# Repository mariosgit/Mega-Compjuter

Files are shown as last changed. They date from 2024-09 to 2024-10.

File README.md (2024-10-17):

# MEGA CompJU+TEr

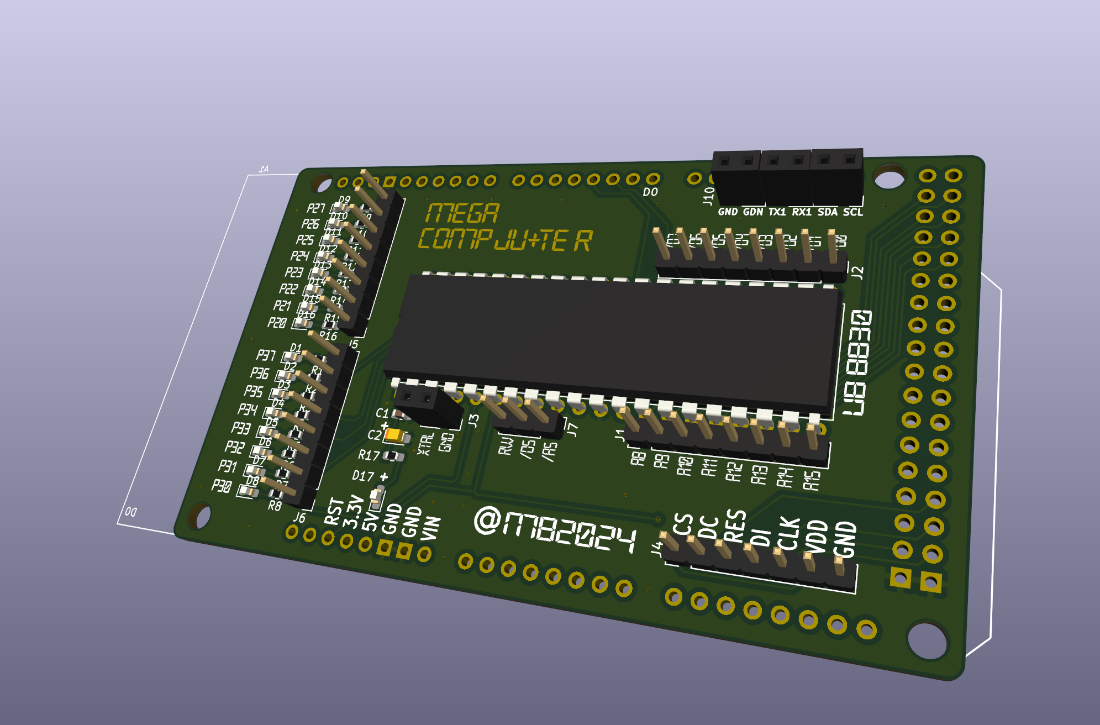
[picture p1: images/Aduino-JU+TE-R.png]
bild


# Status

Just an Idee. Made a basic PCB. Started experimenting...

# Wath's this ?

Arduino MEGA Shield with a UB8830 on top. The UB8833 is a Ostblock version of a Zilog Z8682 with a view quirks.

A bit like these things... http://8bitforce.com/projects/retroshield/ [Or here the Z80 code](https://gitlab.com/8bitforce/retroshield-arduino/-/blob/master/kz80/kz80_test/kz80_test.ino?ref_type=heads)

### Bugs / Improvements

* UB8833 reset(pin6) to some pin(45) ! keep it low until all ports initialize.
* LEDs for AS,RW,DS ?
* Fuse ? The Z8 needs 180mA !?

# Software

From Z8 datasheet...

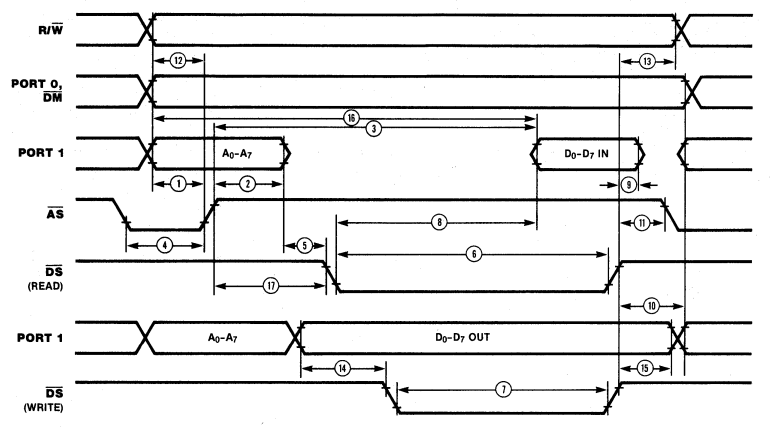
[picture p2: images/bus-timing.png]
bustiming


* When AS goes LOW->HI latch the low adr byte. And read and keep RW flag.
* When DS goes HIGH->LOW and RW is reading (HIGH) put data on the bus. 
* When DS goes low and writing, read the data, do something e.g. save to ram.
* Turn of Data output ??? When ??? Read data to DS 1 hold time is 0, so turn it off after DS goes high.

### Reset

8833 RESET-Eingang (vgl . Kapitel 1) .
Hat er nach eingeschwungene r
Spannungs- und Taktversorgun g
für mindestens **18** Taktperiode n
Nullpegel, erzeugt er im Innere n
des Einchip-Mikrorechners einige
festgelegte Zustände . 

in kurzes Pro-
gramm ab %000C im Test-ROM
konfiguriert Port 0, Port 1 und
P34 für den Anschluß des exter-
nen Speichers und springt au f
Adresse %0812

Der UB 8830 D
(UB 8831 D) besitzt auch be i
„normalem” Rücksetzen die ge-
nannten Interruptvektoren un d
springt auf die Adresse %0812,
wenn dort kein RAM bestückt is t
und P32 keine Verbindung zu P35
hat. 

Der Einchip-
Mikrorechner besitzt ein Test-
programm im internen ROM,
das sich für unsere Zwecke gut
ausnutzen läßt. Damit es vom
Prozessor ausgeführt wird, muß
eine Drahtbrücke die Port
Anschlüsse P32 und P35 ver-
binden. .......  0-Impulse
mit einer Breite von 11 μs
erscheinen. Jede Abweichung
von dieser Regel deutet auf
eine Fehlverbindung zwischen
benachbarten Leiterzügen. Bei
Inbetriebnahme mit Kopfhörer
o. ä. müssen diese 16 An-
schlüsse mit gleichlauten 5,45-
kHz-Tönen 

Der laeuft mit 8mhz, auf dem Arduino mit 70khz, Faktor 114, 1254us.

### First something ?

after applying reset for at least 3 clocks it started doing things
* AS, DS, RW go up and down
* But no data on the bus !? -> could the thing be running it's internal ROM first ? Then there should be a addr=0x0800 (ext reset vector) comming up some time.. When it reads 0 it would start @0 again ???
* Oszi say it starts reading and writing to 0x1012 after about 173 initial clocks. it writes 0xff ?

# PCB

| ATMega Pin Port | UB8833 | Comments |
|---|---|---|
| PA | AdrHi | hi adr byte |
| PC | AdrLow/Data bus | multiplexed Data/Adr bus |
| | | |
| D2(int0) | AS | Adr strobe, Lo->Hi store the low adr |
| D3(int1) | DS | Data strobe, ?? |
| | | |
| D46/PL3(pwm pin) | XTAL | Clock |
| D47/PL2 | RW | Read/Write indication |

| ATMega Pin | Display |
|---|---|
| D53 | CS |
| D49 | DC |
| D51(mosi) | DI |
| D52(sclk) | CLK |

# Refs

https://github.com/boert/JU-TE-Computer

https://hc-ddr.hucki.net/wiki/doku.php/tiny/dokumentation 

https://www.robotrontechnik.de/html/forum/thwb/showtopic.php?threadid=16374

https://hackaday.com/2020/07/17/a-z80-board-with-very-few-parts/

http://bitsavers.informatik.uni-stuttgart.de/components/zilog/z8/Z8681_Data_Sheet_Mar83.pdf

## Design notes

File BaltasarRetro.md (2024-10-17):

From [Arduino and ZiLOG Z80](https://baltazarstudios.com/webshare/Z80_dongle.ino.html)

```
//------------------------------------------------------------------------
// This Arduino sketch should be used with a Mega board connected to a
// dongle hosting a Z80 CPU. The Arduino fully controls and senses all
// Z80 CPU pins. This software runs physical Z80 CPU by providing clock
// ticks and setting various control pins.
//
// There is a limited RAM buffer simulated by this sketch. All Z80 memory
// accesses are directed to use that buffer.
//
// Address and data buses from Z80 are connected to analog Arduino pins.
// Along with a resistor network on the dongle, this allows the software
// to sense when Z80 tri-states those two buses.
//
// Notes:
//      - Use serial set to 115200
//      - In the Arduino serial monitor window, set line ending to "CR"
//      - Memory access is simulated using a 256-byte pseudo-RAM memory
//      - I/O map is _not_ implemented. Reads will return whatever happens
//        to be on the data bus
//
// Copyright 2014 by Goran Devic
// This source code is released under the GPL v2 software license.
//------------------------------------------------------------------------
#include <stdarg.h>
#include "WString.h"

// Define Arduino Mega pins that are connected to a Z80 dongle board.
// Pin numbers appear out-of-order, but they cleanly connect in complete
// blocks to sets of pins on Arduino Mega! This will become obvious once
// you start connecting them...
#define DB0         A9      // DB pin line-up on a Z80 is a bit swizzled...
#define DB1         A8
#define DB2         A11
#define DB3         A14
#define DB4         A15
#define DB5         A13
#define DB6         A12
#define DB7         A10
// Address bus pins from Z80 are connected to A0..A7 on Arduino.

#define INT         52      // This is a block of control signals from the
#define NMI         50      // bottom-left corner of Z80
#define HALT        48
#define MREQ        46
#define IORQ        44

#define RFSH        53      // This is a block of control signals from the
#define M1          51      // bottom-right corner of Z80
#define RESET       49
#define BUSRQ       47
#define WAIT        45
#define BUSAK       43
#define WR          41
#define RD          39

#define CLK         13      // Clock is also toggling Arduino LED (fast, though)

// Tri-state detection values: the values that are read on analog pins
// sensing the "high-Z" will differ based on the resistor values that make
// up your voltage divider. Print your particular readings and adjust these:
#define HI_Z_LOW    50      // Upper "0" value; low tri-state boundary
#define HI_Z_HIGH   600     // Low "1" value; upper tri-state boundary

// Control *output* pins of Z80, we read them into these variables
int  halt;
int  mreq;
int  iorq;
int  rfsh;
int  m1;
int  busak;
int  wr;
int  rd;

// Control *input* pins of Z80, we write them into the dongle
int zint = 1;
int nmi = 1;
int reset = 1;
int busrq = 1;
int wait = 1;

// Content of address and data wires
int ab;
byte db;

// Clock counter after reset
int clkCount;
int clkCountHi;

// T-cycle counter
int T;
int Mlast;

// M1-cycle counter
int m1Count;

// Detection if the address or data bus is tri-stated
bool abTristated = false;
bool dbTristated = false;

// Simulation control variables
bool running = 1;           // Simulation is running or is stopped
int traceShowBothPhases;    // Show both phases of a clock cycle
int traceRefresh;           // Trace refresh cycles
int tracePause;             // Pause for a key press every so many clocks
int tracePauseCount;        // Current clock count for tracePause
int stopAtClk;              // Stop the simulation after this many clocks
int stopAtM1;               // Stop at a specific M1 cycle number
int stopAtHalt;             // Stop when HALT signal gets active
int intAtClk;               // Issue INT signal at that clock number
int nmiAtClk;               // Issue NMI signal at that clock number
int busrqAtClk;             // Issue BUSRQ signal at that clock number
int resetAtClk;             // Issue RESET signal at that clock number
int waitAtClk;              // Issue WAIT signal at that clock number
int clearAtClk;             // Clear all control signals at that clock number
byte iorqVector;            // Push IORQ vector (default is FF)

// Buffer containing RAM memory for Z80 to access
byte ram[256];

// Temp buffer to store input line
#define TEMP_SIZE   512
char temp[TEMP_SIZE];

// Temp buffer to store extra dump information
char extraInfo[64] = { "" };

// Utility function to provide a meaningful printf to a serial port
void p(char *fmt, ... ){
    char tmp[256];          // resulting string limited to 256 chars
    va_list args;
    va_start (args, fmt );
    vsnprintf(tmp, 256, fmt, args);
    va_end (args);
    Serial.print(tmp);
}

// Read and return one ASCII hex value from a string
byte hex(char *s){
    byte nibbleH = (*s - '0') & ~(1<<5);
    byte nibbleL = (*(s+1) - '0') & ~(1<<5);
    if (nibbleH>9) nibbleH -= 7;
    if (nibbleL>9) nibbleL -= 7;
    return (nibbleH << 4) | nibbleL;
}

// Read and return one ASCII hex value from a temp buffer given the index
// of that hex number. This is used only to read Intel HEX format buffer.
byte hexFromTemp(char *pTemp, int index)
{
    int start = (index*2)+1;
    return hex(pTemp + start);
}

// -----------------------------------------------------------
// Arduino initialization entry point
// -----------------------------------------------------------
void setup()
{
    Serial.begin(115200);
    Serial.flush();
    Serial.setTimeout(1000*60*60);

    ResetSimulationVars();

    // By default, all Arduino pins are set as inputs
    // Configure all output pins, *inputs* into Z80
    pinMode(CLK, OUTPUT);
    digitalWrite(CLK, HIGH);
    pinMode(INT, OUTPUT);
    pinMode(NMI, OUTPUT);
    pinMode(RESET, OUTPUT);
    pinMode(BUSRQ, OUTPUT);
    pinMode(WAIT, OUTPUT);
    WriteControlPins();

    // Perform a Z80 CPU reset
    DoReset();
}

// Resets all simulation variables to their defaults
void ResetSimulationVars()
{
    traceShowBothPhases = 0;// Show both phases of a clock cycle
    traceRefresh = 1;       // Trace refresh cycles
    tracePause = -1;        // Pause for a keypress every so many clocks
    stopAtClk = 40;         // Stop the simulation after this many clocks
    stopAtM1 = -1;          // Stop at a specific M1 cycle number
    stopAtHalt = 1;         // Stop when HALT signal gets active
    intAtClk = -1;          // Issue INT signal at that clock number
    nmiAtClk = -1;          // Issue NMI signal at that clock number
    busrqAtClk = -1;        // Issue BUSRQ signal at that clock number
    resetAtClk = -1;        // Issue RESET signal at that clock number
    waitAtClk = -1;         // Issue WAIT signal at that clock number
    clearAtClk = -1;        // Clear all control signals at that clock number
    iorqVector = 0xFF;      // Push IORQ vector
}

// Issue a RESET sequence to Z80 and reset internal counters
void DoReset()
{
    p("\r\n:Starting the clock\r\n");
    digitalWrite(RESET, LOW);    delay(1);
    // Reset should be kept low for 3 full clock cycles
    for(int i=0; i<3; i++)
    {
        digitalWrite(CLK, HIGH); delay(1);
        digitalWrite(CLK, LOW);  delay(1);
    }
    p(":Releasing RESET\r\n");
    digitalWrite(RESET, HIGH);   delay(1);
    // Do not count initial 2 clocks after the reset
    clkCount = -2;
    T = 0;
    Mlast = 1;
    tracePauseCount = 0;
    m1Count = 0;
}

// Write all control pins into the Z80 dongle
void WriteControlPins()
{
    digitalWrite(INT, zint ? HIGH : LOW);
    digitalWrite(NMI, nmi ? HIGH : LOW);
    digitalWrite(RESET, reset ? HIGH : LOW);
    digitalWrite(BUSRQ, busrq ? HIGH : LOW);
    digitalWrite(WAIT,  wait ? HIGH : LOW);
}

// Set new data value into the Z80 data bus
void SetDataToDB(byte data)
{
    pinMode(DB0, OUTPUT);
    pinMode(DB1, OUTPUT);
    pinMode(DB2, OUTPUT);
    pinMode(DB3, OUTPUT);
    pinMode(DB4, OUTPUT);
    pinMode(DB5, OUTPUT);
    pinMode(DB6, OUTPUT);
    pinMode(DB7, OUTPUT);

    digitalWrite(DB0, (data & (1<<0)) ? HIGH : LOW);
    digitalWrite(DB1, (data & (1<<1)) ? HIGH : LOW);
    digitalWrite(DB2, (data & (1<<2)) ? HIGH : LOW);
    digitalWrite(DB3, (data & (1<<3)) ? HIGH : LOW);
    digitalWrite(DB4, (data & (1<<4)) ? HIGH : LOW);
    digitalWrite(DB5, (data & (1<<5)) ? HIGH : LOW);
    digitalWrite(DB6, (data & (1<<6)) ? HIGH : LOW);
    digitalWrite(DB7, (data & (1<<7)) ? HIGH : LOW);
    db = data;
    dbTristated = false;
}

// Read Z80 data bus and store into db variable
void GetDataFromDB()
{
    pinMode(DB0, INPUT);
    pinMode(DB1, INPUT);
    pinMode(DB2, INPUT);
    pinMode(DB3, INPUT);
    pinMode(DB4, INPUT);
    pinMode(DB5, INPUT);
    pinMode(DB6, INPUT);
    pinMode(DB7, INPUT);

    digitalWrite(DB0, LOW);
    digitalWrite(DB1, LOW);
    digitalWrite(DB2, LOW);
    digitalWrite(DB3, LOW);
    digitalWrite(DB4, LOW);
    digitalWrite(DB5, LOW);
    digitalWrite(DB6, LOW);
    digitalWrite(DB7, LOW);

    // Detect if the data bus is tri-stated
    delay(1);
    int test0 = analogRead(DB0);
    // These numbers might need to be adjusted for each Arduino board
    dbTristated = test0>HI_Z_LOW && test0<HI_Z_HIGH;

    byte d0 = digitalRead(DB0);
    byte d1 = digitalRead(DB1);
    byte d2 = digitalRead(DB2);
    byte d3 = digitalRead(DB3);
    byte d4 = digitalRead(DB4);
    byte d5 = digitalRead(DB5);
    byte d6 = digitalRead(DB6);
    byte d7 = digitalRead(DB7);
    db = (d7<<7)|(d6<<6)|(d5<<5)|(d4<<4)|(d3<<3)|(d2<<2)|(d1<<1)|d0;
}

// Read a value of Z80 address bus and store it into the ab variable.
// In addition, try to detect when a bus is tri-stated and write 0xFFF if so.
void GetAddressFromAB()
{
    // Detect if the address bus is tri-stated
    int test0 = analogRead(A0);
    // These numbers might need to be adjusted for each Arduino board
    abTristated = test0>HI_Z_LOW && test0<HI_Z_HIGH;

    int a0 = digitalRead(A0);
    int a1 = digitalRead(A1);
    int a2 = digitalRead(A2);
    int a3 = digitalRead(A3);
    int a4 = digitalRead(A4);
    int a5 = digitalRead(A5);
    int a6 = digitalRead(A6);
    int a7 = digitalRead(A7);
    ab = (a7<<7)|(a6<<6)|(a5<<5)|(a4<<4)|(a3<<3)|(a2<<2)|(a1<<1)|a0;
}

// Read all control pins on the Z80 and store them into internal variables
void ReadControlState()
{
    halt  = digitalRead(HALT);
    mreq  = digitalRead(MREQ);
    iorq  = digitalRead(IORQ);
    rfsh  = digitalRead(RFSH);
    m1    = digitalRead(M1);
    busak = digitalRead(BUSAK);
    wr    = digitalRead(WR);
    rd    = digitalRead(RD);
}

// Dump the Z80 state as stored in internal variables
void DumpState(bool suppress)
{
    if (!suppress)
    {
        // Select your character for tri-stated bus
        char abStr[4] = { "---" };
        char dbStr[3] = { "--" };
        if (!abTristated) sprintf(abStr, "%03X", ab);
        if (!dbTristated) sprintf(dbStr, "%02X", db);
        if (T==1 && clkCountHi)
            p("-----------------------------------------------------------+\r\n");
        p("#%03d%c T%-2d AB:%s DB:%s  %s %s %s %s %s %s %s %s |%s%s%s%s %s\r\n",
        clkCount<0? 0 : clkCount, clkCountHi ? 'H' : 'L', T,
        abStr, dbStr,
        m1?"  ":"M1", rfsh?"    ":"RFSH", mreq?"    ":"MREQ", rd?"  ":"RD", wr?"  ":"WR", iorq?"    ":"IORQ", busak?"     ":"BUSAK",halt?"    ":"HALT",
        zint?"":"[INT]", nmi?"":"[NMI]", busrq?"":"[BUSRQ]", wait?"":"[WAIT]",
        extraInfo);
    }
    extraInfo[0] = 0;
}

// -----------------------------------------------------------
// Main loop routine runs over and over again forever
// -----------------------------------------------------------
void loop()
{
    //--------------------------------------------------------
    // Clock goes high
    //--------------------------------------------------------
    delay(1); digitalWrite(CLK, HIGH); delay(1);

    clkCountHi = 1;
    clkCount++;
    T++;
    tracePauseCount++;
    ReadControlState();
    GetAddressFromAB();
    if (Mlast==1 && m1==0)
        T = 1, m1Count++;
    Mlast = m1;
    bool suppressDump = false;
    if (!traceRefresh & !rfsh) suppressDump = true;

    // If the number of M1 cycles has been reached, skip the rest since we dont
    // want to execute this M1 phase
    if (m1Count==stopAtM1)
    {
        sprintf(extraInfo, "Number of M1 cycles reached"), running = false;
        p("-----------------------------------------------------------+\r\n");
        goto control;
    }

    // If the address is tri-stated, skip checking various combinations of
    // control signals since they may also be floating and we can't detect that
    if (!abTristated)
    {
        // Simulate read from RAM
        if (!mreq && !rd)
        {
            SetDataToDB(ram[ab & 0xFF]);
            if (!m1)
                sprintf(extraInfo, "Opcode read from %03X -> %02X", ab, ram[ab & 0xFF]);
            else
                sprintf(extraInfo, "Memory read from %03X -> %02X", ab, ram[ab & 0xFF]);
        }
        else
        // Simulate interrupt requesting a vector
        if (!m1 && !iorq)
        {
            SetDataToDB(iorqVector);
            sprintf(extraInfo, "Pushing vector %02X", iorqVector);
        }
        else
            GetDataFromDB();

        // Simulate write to RAM
        if (!mreq && !wr)
        {
            ram[ab & 0xFF] = db;
            sprintf(extraInfo, "Memory write to  %03X <- %02X", ab, db);
        }

        // Detect I/O read: We don't place anything on the bus
        if (!iorq && !rd)
        {
            sprintf(extraInfo, "I/O read from %03X", ab);
        }

        // Detect I/O write
        if (!iorq && !wr)
        {
            sprintf(extraInfo, "I/O write to %03X <- %02X", ab, db);
        }

        // Capture memory refresh cycle
        if (!mreq && !rfsh)
        {
            sprintf(extraInfo, "Refresh address  %03X", ab);
        }
    }
    else
        GetDataFromDB();

    DumpState(suppressDump);

    // If the user wanted to pause simulation after a certain number of
    // clocks, handle it here. If the key pressed to continue was not Enter,
    // stop the simulation to issue that command
    if (tracePause==tracePauseCount)
    {
        while(Serial.available()==0) ;
        if (Serial.peek()!='\r')
            sprintf(extraInfo, "Continue keypress was not Enter"), running = false;
        else
            Serial.read();
        tracePauseCount = 0;
    }

    //--------------------------------------------------------
    // Clock goes low
    //--------------------------------------------------------
    delay(1); digitalWrite(CLK, LOW); delay(1);

    clkCountHi = 0;
    if (traceShowBothPhases)
    {
        ReadControlState();
        GetAddressFromAB();
        DumpState(suppressDump);
    }

    // Perform various actions at the requested clock number
    // if the count is positive (we start it at -2 to skip initial 2T)
    if (clkCount>=0)
    {
        if (clkCount==intAtClk) zint = 0;
        if (clkCount==nmiAtClk) nmi = 0;
        if (clkCount==busrqAtClk) busrq = 0;
        if (clkCount==resetAtClk) reset = 0;
        if (clkCount==waitAtClk) wait = 0;
        // De-assert all control pins at this clock number
        if (clkCount==clearAtClk)
            zint = nmi = busrq = reset = wait = 1;
        WriteControlPins();

        // Stop the simulation under some conditions
        if (clkCount==stopAtClk)
            sprintf(extraInfo, "Number of clocks reached"), running = false;
        if (stopAtHalt&!halt)
            sprintf(extraInfo, "HALT instruction"), running = false;
    }

    //--------------------------------------------------------
    // Trace/simulation control handler
    //--------------------------------------------------------
control:
    if (!running)
    {
        p(":Simulation stopped: %s\r\n", extraInfo);
        extraInfo[0] = 0;
        digitalWrite(CLK, HIGH);
        zint = nmi = busrq = wait = 1;
        WriteControlPins();

        while(!running)
        {
            // Expect a command from the serial port
            if (Serial.available()>0)
            {
                memset(temp, 0, TEMP_SIZE);
                Serial.readBytesUntil('\r', temp, TEMP_SIZE-1);

                // Option ":"  : this is not really a user option. This is used to
                //               Intel HEX format values into the RAM buffer
                // Multiple lines may be pasted. They are separated by a space character.
                char *pTemp = temp;
                while (*pTemp==':')
                {
                    byte bytes = hexFromTemp(pTemp, 0);
                    if (bytes>0)
                    {
                        int address = (hexFromTemp(pTemp, 1)<<8) + hexFromTemp(pTemp, 2);
                        byte recordType = hexFromTemp(pTemp, 3);
                        p("%04X:", address);
                        for (int i=0; i<bytes; i++)
                        {
                            ram[(address + i) & 0xFF] = hexFromTemp(pTemp, 4+i);
                            p(" %02X", hexFromTemp(pTemp, 4+i));
                        }
                        p("\r\n");
                    }
                    pTemp += bytes*2 + 12;  // Skip to the next possible line of hex entry
                }
                // Option "r"  : reset and run the simulation
                if (temp[0]=='r')
                {
                    // If the variable 9 (Issue RESET) is not set, perform a RESET and run the simulation.
                    // If the variable was set, skip reset sequence since we might be testing it.
                    if (resetAtClk<0)
                        DoReset();
                    running = true;
                }
                // Option "sc" : clear simulation variables to their default values
                if (temp[0]=='s' && temp[1]=='c')
                {
                    ResetSimulationVars();
                    temp[1] = 0;            // Proceed to dump all variables...
                }
                // Option "s"  : show and set internal control variables
                if (temp[0]=='s' && temp[1]!='c')
                {
                    // Show or set the simulation parameters
                    int var = 0, value;
                    int args = sscanf(&temp[1], "%d %d\r\n", &var, &value);
                    // Parameter for the option #12 is read in as a hex; others are decimal by default
                    if (var==12)
                        args = sscanf(&temp[1], "%d %x\r\n", &var, &value);
                    if (args==2)
                    {
                        if (var==0) traceShowBothPhases = value;
                        if (var==1) traceRefresh = value;
                        if (var==2) tracePause = value;
                        if (var==3) stopAtClk = value;
                        if (var==4) stopAtM1 = value;
                        if (var==5) stopAtHalt = value;
                        if (var==6) intAtClk = value;
                        if (var==7) nmiAtClk = value;
                        if (var==8) busrqAtClk = value;
                        if (var==9) resetAtClk = value;
                        if (var==10) waitAtClk = value;
                        if (var==11) clearAtClk = value;
                        if (var==12) iorqVector = value & 0xFF;
                    }
                    p("------ Simulation variables ------\r\n");
                    p("#0  Trace both clock phases  = %d\r\n", traceShowBothPhases);
                    p("#1  Trace refresh cycles     = %d\r\n", traceRefresh);
                    p("#2  Pause for keypress every = %d\r\n", tracePause);
                    p("#3  Stop after clock #       = %d\r\n", stopAtClk);
                    p("#4  Stop after # M1 cycles   = %d\r\n", stopAtM1);
                    p("#5  Stop at HALT             = %d\r\n", stopAtHalt);
                    p("#6  Issue INT at clock #     = %d\r\n", intAtClk);
                    p("#7  Issue NMI at clock #     = %d\r\n", nmiAtClk);
                    p("#8  Issue BUSRQ at clock #   = %d\r\n", busrqAtClk);
                    p("#9  Issue RESET at clock #   = %d\r\n", resetAtClk);
                    p("#10 Issue WAIT at clock #    = %d\r\n", waitAtClk);
                    p("#11 Clear all at clock #     = %d\r\n", clearAtClk);
                    p("#12 Push IORQ vector #(hex)  = %2X\r\n", iorqVector);
                }
                // Option "m"  : dump RAM memory
                if (temp[0]=='m' && temp[1]!='c')
                {
                    // Dump the content of a RAM buffer
                    p("    00 01 02 03 04 05 06 07 08 09 0A 0B 0C 0D 0E 0F\r\n");
                    p("   +-----------------------------------------------\r\n");
                    for(int i=0; i<16; i++)
                    {
                        p("%02X |", i);
                        for(int j=0; j<16; j++)
                        {
                            p("%02X ", ram[i*16+j]);
                        }
                        p("\r\n");
                    }
                }
                // Option "mc"  : clear RAM memory
                if (temp[0]=='m' && temp[1]=='c')
                {
                    memset(ram, 0, sizeof(ram));
                    p("RAM cleared\r\n");
                }
                // Option "?"  : print help
                if (temp[0]=='?' || temp[0]=='h')
                {
                    p("s            - show simulation variables\r\n");
                    p("s #var value - set simulation variable number to a value\r\n");
                    p("sc           - clear simulation variables to their default values\r\n");
                    p("r            - restart the simulation\r\n");
                    p(":INTEL-HEX   - reload RAM buffer with a given data stream\r\n");
                    p("m            - dump the content of the RAM buffer\r\n");
                    p("mc           - clear the RAM buffer\r\n");
                }
            }
        }
    }
}

```

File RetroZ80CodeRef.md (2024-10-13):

# Ref..

 http://8bitforce.com/projects/retroshield/ [Or here the Z80 code](https://gitlab.com/8bitforce/retroshield-arduino/-/blob/master/kz80/kz80_test/kz80_test.ino?ref_type=heads)

```
////////////////////////////////////////////////////////////////////
// Z80 RetroShield Code
// 2019/02/11
// Version 0.1
// Erturk Kocalar

// The MIT License (MIT)

// Copyright (c) 2019 Erturk Kocalar, 8Bitforce.com

// Permission is hereby granted, free of charge, to any person obtaining a copy
// of this software and associated documentation files (the "Software"), to deal
// in the Software without restriction, including without limitation the rights
// to use, copy, modify, merge, publish, distribute, sublicense, and/or sell
// copies of the Software, and to permit persons to whom the Software is
// furnished to do so, subject to the following conditions:

// The above copyright notice and this permission notice shall be included in all
// copies or substantial portions of the Software.

// THE SOFTWARE IS PROVIDED "AS IS", WITHOUT WARRANTY OF ANY KIND, EXPRESS OR
// IMPLIED, INCLUDING BUT NOT LIMITED TO THE WARRANTIES OF MERCHANTABILITY,
// FITNESS FOR A PARTICULAR PURPOSE AND NONINFRINGEMENT. IN NO EVENT SHALL THE
// AUTHORS OR COPYRIGHT HOLDERS BE LIABLE FOR ANY CLAIM, DAMAGES OR OTHER
// LIABILITY, WHETHER IN AN ACTION OF CONTRACT, TORT OR OTHERWISE, ARISING FROM,
// OUT OF OR IN CONNECTION WITH THE SOFTWARE OR THE USE OR OTHER DEALINGS IN THE
// SOFTWARE.

////////////////////////////////////////////////////////////////////
// include the library code:
////////////////////////////////////////////////////////////////////

#include <LiquidCrystal.h>
#include <avr/pgmspace.h>

// Set this to enable outputing ADDR, DATA, Freq
// on LCD and use UP/DOWN for controlling RESET#.
#define USE_LCDKEYPAD 0

// Set this to output memory operations during timer clock.
// warning: this will slow down the timer interrupt, so adjust clock
//          freq accordingly.
#define outputDEBUG 0

////////////////////////////////////////////////////////////////////
// Configuration
////////////////////////////////////////////////////////////////////

/*
  The circuit:
 * LCD RS pin to digital pin 12
 * LCD Enable pin to digital pin 11
 * LCD D4 pin to digital pin 5
 * LCD D5 pin to digital pin 4
 * LCD D6 pin to digital pin 3
 * LCD D7 pin to digital pin 2
 * LCD R/W pin to ground
 * 10K resistor:
 * ends to +5V and ground
 * wiper to LCD VO pin (pin 3)
*/

#define LCD_RS  8
#define LCD_EN  9
#define LCD_D4  4
#define LCD_D5  5
#define LCD_D6  6
#define LCD_D7  7
#define LCD_BL  10
#define LCD_BTN  0

#define NUM_KEYS   5
#define BTN_DEBOUNCE 10
#define BTN_RIGHT  0
#define BTN_UP     1
#define BTN_DOWN   2
#define BTN_LEFT   3
#define BTN_SELECT 4
const int adc_key_val[NUM_KEYS] = { 30, 180, 360, 535, 760 };
int key = -1;
int oldkey = -1;
boolean BTN_PRESS = 0;
boolean BTN_RELEASE = 0;

////////////////////////////////////////////////////////////////////
// initialize the library with the numbers of the interface pins
LiquidCrystal lcd(LCD_RS, LCD_EN, LCD_D4, LCD_D5, LCD_D6, LCD_D7);

////////////////////////////////////////////////////////////////////
// My Variables
////////////////////////////////////////////////////////////////////

int backlightSet = 25;

////////////////////////////////////////////////////////////////////
// Z80 DEFINITIONS
////////////////////////////////////////////////////////////////////

// Z80 HW CONSTRAINTS
// !!! TODO !!!
// 1- RESET_N must be asserted at least 2 clock cycles.
// 2- CLK can not be low more than 5 microseconds.  Can be high indefinitely.
//

////////////////////////////////////////////////////////////////////
// Monitor Code
////////////////////////////////////////////////////////////////////
// static const unsigned char 
PROGMEM const unsigned char rom_bin[] = {
 0x31,0xFF,0x83,0xED,0x56,0xFB,0x3E,0x4D,
 0xD3,0x01,0x3E,0x37,0xD3,0x01,0xC3,0x3C,
 0x00,0x00,0x00,0x00,0x00,0x00,0x00,0x00,
 0x00,0x00,0x00,0x00,0x00,0x00,0x00,0x00,
 0x00,0x00,0x00,0x00,0x00,0x00,0x00,0x00,
 0x00,0x00,0x00,0x00,0x00,0x00,0x00,0x00,
 0x00,0x00,0x00,0x00,0x00,0x00,0x00,0x00,
 0xF3,0xFB,0xED,0x4D,0x21,0x51,0x00,0x06,
 0x1D,0x7E,0xCD,0x6E,0x00,0x23,0x10,0xF9,
 0xCD,0x7A,0x00,0xCD,0x6E,0x00,0xC3,0x48,
 0x00,0x0A,0x0D,0x54,0x58,0x44,0x3A,0x20,
 0x20,0x20,0x20,0x0A,0x0D,0x52,0x58,0x44,
 0x3A,0x20,0x20,0x20,0x0A,0x0D,0x52,0x65,
 0x61,0x64,0x79,0x3E,0x0A,0x0D,0xF5,0xDB,
 0x01,0xE6,0x01,0xCA,0x6F,0x00,0xF1,0xD3,
 0x00,0xC9,0xDB,0x01,0xE6,0x02,0xCA,0x7A,
 0x00,0xDB,0x00,0xC9
};

////////////////////////////////////////////////////////////////////
// MEMORY LAYOUT
////////////////////////////////////////////////////////////////////

// ROM(s) (Monitor)
#define ROM_START   0x0000
#define ROM_END     (ROM_START+sizeof(rom_bin))

// RAM (4KB)
#define RAM_START   0x8000
#define RAM_END     0x8FFF
byte    RAM[RAM_END-RAM_START+1];

////////////////////////////////////////////////////////////////////
// 8251 Peripheral
// emulate just enough so keyboard/display works thru serial port.
////////////////////////////////////////////////////////////////////
//

#define ADDR_8251_DATA          0x00
#define ADDR_8251_MODCMD        0x01

#define STATE_8251_RESET        0x01
#define STATE_8251_INITIALIZED  0x00
#define CMD_8251_INTERNAL_RESET 0x40
#define CMD_8251_RTS            0x20
#define CMD_8251_DTR            0x02
#define STAT_8251_TxRDY         0x01
#define STAT_8251_RxRDY         0x02
#define STAT_8251_TxE           0x04
#define STAT_DSR                0x80

byte reg8251_STATE;      // register to keep track of 8251 state: reset or initialized
byte reg8251_MODE;
byte reg8251_COMMAND;
byte reg8251_STATUS;
byte reg8251_DATA;

////////////////////////////////////////////////////////////////////
// Z80 Processor Control
////////////////////////////////////////////////////////////////////
//

/* Digital Pin Assignments */
#define DATA_OUT (PORTL)
#define DATA_IN  (PINL)
#define ADDR_H   (PINC)
#define ADDR_L   (PINA)
#define ADDR     ((unsigned int) (ADDR_H << 8 | ADDR_L))

#define uP_RESET_N  38
#define uP_MREQ_N   41
#define uP_IORQ_N   39
#define uP_RD_N     53
#define uP_WR_N     40
#define uP_NMI_N    51
#define uP_INT_N    50
#define uP_CLK      52

// Fast routines to drive clock signals high/low; faster than digitalWrite
// required to meet >100kHz clock
//
#define CLK_HIGH      (PORTB = PORTB | 0x02)
#define CLK_LOW       (PORTB = PORTB & 0xFC)
#define STATE_RD_N    (PINB & 0x01)
#define STATE_WR_N    (PING & 0x02)
#define STATE_MREQ_N  (PING & 0x01)
#define STATE_IORQ_N  (PING & 0x04)

#define DIR_IN  0x00
#define DIR_OUT 0xFF
#define DATA_DIR   DDRL
#define ADDR_H_DIR DDRC
#define ADDR_L_DIR DDRA

unsigned long clock_cycle_count;
unsigned long uP_start_millis;
unsigned long uP_stop_millis;
unsigned int  uP_ADDR;
byte uP_DATA;

void uP_init()
{
  // Set directions
  DATA_DIR = DIR_IN;
  ADDR_H_DIR = DIR_IN;
  ADDR_L_DIR = DIR_IN;
  
  pinMode(uP_RESET_N, OUTPUT);
  pinMode(uP_WR_N, INPUT);
  pinMode(uP_RD_N, INPUT);
  pinMode(uP_MREQ_N, INPUT);
  pinMode(uP_IORQ_N, INPUT);
  pinMode(uP_INT_N, OUTPUT);
  pinMode(uP_NMI_N, OUTPUT);
  pinMode(uP_CLK, OUTPUT);
  
  uP_assert_reset();
  digitalWrite(uP_CLK, LOW);
  
  clock_cycle_count = 0;
  uP_start_millis = millis();
  // Next State
}

void intel8251_init()
{
  reg8251_STATE     = STATE_8251_RESET;
  reg8251_MODE      = 0b01001101;       // async mode: 1x baudrate, 8n1
  reg8251_COMMAND   = 0b00100111;       // enable tx/rx; assert DTR & RTS
  reg8251_STATUS    = 0b10000101;       // TxRDY, TxE, DSR (ready for operation). RxRDY=0
  reg8251_DATA      = 0x00;
}

void uP_assert_reset()
{
  // Drive RESET conditions
  digitalWrite(uP_RESET_N, LOW);
  digitalWrite(uP_INT_N, HIGH);
  digitalWrite(uP_NMI_N, HIGH);
}

void uP_release_reset()
{
  // Drive RESET conditions
  digitalWrite(uP_RESET_N, HIGH);
}

////////////////////////////////////////////////////////////////////
// Processor Control Loop
////////////////////////////////////////////////////////////////////
// This is where the action is.
// it reads processor control signals and acts accordingly.
//
// Z80 takes multiple cycles to accomplish each rd/write.
// so if we act on IORQ, RD, WR at every clock cycle, then
// we perform erroneous extra IO read/writes.
// FIX WR: perform IO write only on IORQ/WR falling edge.
// FIX RD: perform IO read only on IORQ/RD falling edge.
byte prevIORQ = 0;
byte prevMREQ = 0;
byte prevDATA = 0;

ISR(TIMER1_COMPA_vect)
{ 
  CLK_HIGH;    // CLK goes high
  
  uP_ADDR = ADDR;
  
  // unlike memory mapped devices in 6502 & 6809,
  // Z80 bus has two modes: Memory (MREQ_N) and IO (IORQ_N)

  //////////////////////////////////////////////////////////////////////
  // Memory Access?
  if (!STATE_MREQ_N)    
  {

    // Memory Read?
    if (!STATE_RD_N)
    {
      // change DATA port to output to uP:
      DATA_DIR = DIR_OUT;

      // ROM?
      if ( (ROM_START <= uP_ADDR) && (uP_ADDR <= ROM_END) )
        DATA_OUT = pgm_read_byte_near(rom_bin + (uP_ADDR - ROM_START));
      else
      // RAM?
      if ( (uP_ADDR <= RAM_END) && (RAM_START <= uP_ADDR) )
        DATA_OUT = RAM[uP_ADDR - RAM_START];

    } else
    // Write?
    if (!STATE_WR_N)
    {
      // Memory Write
      if ( (RAM_START <= uP_ADDR) && (uP_ADDR <= RAM_END) )
        RAM[uP_ADDR - RAM_START] = DATA_IN;
    }

    if (outputDEBUG)
    {
      char tmp[20];
      sprintf(tmp, "MREQ RW=%0.1X A=%0.4X D=%0.2X\n", STATE_WR_N, uP_ADDR, DATA_OUT);
      Serial.write(tmp);
    }
  } else
  
  //////////////////////////////////////////////////////////////////////
  // IO Access?
  if (!STATE_IORQ_N)
  {    
    // IO Read?
    if (!STATE_RD_N && prevIORQ)    // perform actual read on falling edge
    {
      // change DATA port to output to uP:
      DATA_DIR = DIR_OUT;

      // 8251 access

      if ( ADDR_L == ADDR_8251_DATA)
      {
        // DATA register access
        prevDATA = reg8251_DATA = Serial.read();
        // clear RxRDY bit in 8251
        reg8251_STATUS = reg8251_STATUS & (~STAT_8251_RxRDY);
        // Serial.write("8251 serial read\n");
      }
      else

      if ( ADDR_L == ADDR_8251_MODCMD )
      {
        // Mode/Command Register access
        if (reg8251_STATE == STATE_8251_RESET)
          prevDATA = reg8251_MODE;
        else
          prevDATA = reg8251_STATUS;
      }
      // output data at this cycle too
      DATA_OUT = prevDATA;
    } else
    
    // continuing IO Read?
    if (!STATE_RD_N && !prevIORQ)    // continue output same data
    {
      // change DATA port to output to uP:
      DATA_DIR = DIR_OUT;

      DATA_OUT = prevDATA;
    } else

    // IO Write?
    if (!STATE_WR_N && prevIORQ)      // perform write on falling edge
    {
      // 8251 access
      if (ADDR_L == ADDR_8251_DATA)
      {
        // write to DATA register
        reg8251_DATA = DATA_IN;
        // TODO: Spit byte out to serial
        Serial.write(reg8251_DATA);        
      }
      else
      if ( ADDR_L == ADDR_8251_MODCMD )
        // write to Mode/Command Register
        if (reg8251_STATE == STATE_8251_RESET)
        {
          // 8251 changes from MODE to COMMAND
          reg8251_STATE = STATE_8251_INITIALIZED;
          // we ignore the mode command for now.
          // reg8251_MODE = DATA_IN
          Serial.write("8251 reset\n");
          
        } else {
          // Write to 8251 command register
          reg8251_COMMAND = DATA_IN;
          // TODO: process command sent
        }

    } else
  //////////////////////////////////////////////////////////////////////
    // if (STATE_RD_N && STATE_WR_N)        // 1 && 1
    {
      // Interrupt Mode 2 Acknowledge scenario
      // IORQ asserted, RD & WR not asserted
      // Z80 expects interrupt vector on databus

      // change DATA port to output to uP:
      DATA_DIR = DIR_OUT;

      // default to vector 0
      DATA_OUT = 0;
    }

    if (outputDEBUG)
    {
      char tmp[20];
      sprintf(tmp, "IORQ RW=%0.1X A=%0.4X D=%0.2X\n", STATE_WR_N, uP_ADDR, DATA_OUT);
      Serial.write(tmp);
    }
  }

  prevIORQ = STATE_IORQ_N;
  prevMREQ = STATE_MREQ_N;
  
  //////////////////////////////////////////////////////////////////////
  // start next cycle
  CLK_LOW;    // E goes low

  // one full cycle complete
  clock_cycle_count ++;

  // natural delay for DATA Hold time (t_HR)
  DATA_DIR = DIR_IN;
    
}

////////////////////////////////////////////////////////////////////
// Serial Event
////////////////////////////////////////////////////////////////////

/*
  SerialEvent occurs whenever a new data comes in the
 hardware serial RX.  This routine is run between each
 time loop() runs, so using delay inside loop can delay
 response. Note: Multiple bytes of data may be available.
 */
void serialEvent0() 
{
  if (Serial.available())
  {
    // if (reg8251_STATUS & CMD_8251_RTS)  // read serial byte only if RTS is asserted
    {
      // stop interrupts while changing 8251 guts.
      cli();                            
      
      // convert to uppercase if needed
      // int ch = toupper( Serial.read() );

      // reg8251_DATA = Serial.read();

      // RxRDY bit for cpu
      reg8251_STATUS = reg8251_STATUS | STAT_8251_RxRDY;
      sei();
    }
  }
  return;
}

////////////////////////////////////////////////////////////////////
// int getKey() - LCD/Keyboard function from vendor
////////////////////////////////////////////////////////////////////

int getKey()
{
  key = get_key2();
  if (key != oldkey)
    {
      delay(BTN_DEBOUNCE);
      key = get_key2();
      if (key != oldkey) {
        oldkey = key;
        if (key == -1)
          BTN_RELEASE = 1;
        else
          BTN_PRESS = 1;
      }
    } else {
      BTN_PRESS = 0;
      BTN_RELEASE = 0;
    }
  return (key != -1);
}

int get_key2()
{
  int k;
  int adc_key_in;

  adc_key_in = analogRead( LCD_BTN );
  for( k = 0; k < NUM_KEYS; k++ )
  {
    if ( adc_key_in < adc_key_val[k] )
    {
      return k;
    }
  }
  if ( k >= NUM_KEYS )
    k = -1;
  return k;
}

////////////////////////////////////////////////////////////////////
// Button Press Callbacks - LCD/Keyboard function from vendor
////////////////////////////////////////////////////////////////////

void btn_Pressed_Select()
{
  // toggle LCD brightness
  analogWrite(LCD_BL, (backlightSet = (25 + backlightSet) % 100) );
}

void btn_Pressed_Left()
{
  // Serial.println("Left.");
  digitalWrite(uP_NMI_N, LOW);
}

void btn_Pressed_Right()
{
  // Serial.println("Right.");
  digitalWrite(uP_NMI_N, HIGH);
}

void btn_Pressed_Up()
{
  // Serial.println("Up.");
  
  // release uP_RESET
  digitalWrite(uP_RESET_N, HIGH);
}

void btn_Pressed_Down()
{
  // Serial.println("Down.");
  
  // assert uP_RESET
  digitalWrite(uP_RESET_N, LOW);
  
  // flush serial port
  while (Serial.available() > 0)
    Serial.read();
}

////////////////////////////////////////////////////////////////////
// Setup
////////////////////////////////////////////////////////////////////

void setup() 
{

  Serial.begin(115200);
  
  if (USE_LCDKEYPAD)
  {
    pinMode(LCD_BL, OUTPUT);
    analogWrite(LCD_BL, backlightSet);  
    lcd.begin(16, 2);
  }
  
  // Initialize processor GPIO's
  uP_init();
  intel8251_init();
  
  // Set up timer1 interrupt to handle clock & addr/data in the fastest possible way.
  // timer interrupt also runs in parallel with the loop() function, so we have a
  // simple multi-threading going on :)
  
  cli();
  //set timer1 interrupt at 1Hz
  TCCR1A = 0;// set entire TCCR1A register to 0
  TCCR1B = 0;// same for TCCR1B
  TCNT1  = 0;//initialize counter value to 0
  // set compare match register for 1hz increments
  OCR1A = 20; // 100kHz mode: 19;  // = (16*10^6) / (1*1024) - 1 (must be <65536)
  // turn on CTC mode
  TCCR1B |= (1 << WGM12);
  // Set CS10 and CS12 bits for 1024 prescaler
  // CS12 - CS11 - CS10 Prescalar
  // 1=1/1, 2=1/8, 3=1/64, 4=1/256, 5=1/1024
  TCCR1B |= (1 << CS11);   // 95kHz
  // TCCR1B |= (1<<CS10) | (1<<CS12);   // 0.74kHz
  
  // enable timer compare interrupt
  TIMSK1 |= (1 << OCIE1A);
  sei();

  // delay 250ms so uP sees RESET asserted.
  delay(250);

  Serial.write("init complete\n");
  // Go, go, go
  uP_release_reset();
}

////////////////////////////////////////////////////////////////////
// Loop()
// * This function runs in parallel with timer interrupt handler.
//   i.e. simplest multi-threading.
// * try to be done as quickly as possible so processor does not
//   slow down.
////////////////////////////////////////////////////////////////////

void loop()
{
  if (USE_LCDKEYPAD)
  {
    // Handle key presses
    //
    if ( getKey() ) {
      // button pressed
      if ( BTN_PRESS ) {
        if (key == BTN_SELECT) btn_Pressed_Select();
        if (key == BTN_UP)     btn_Pressed_Up();
        if (key == BTN_DOWN)   btn_Pressed_Down();
        if (key == BTN_LEFT)   btn_Pressed_Left();
        if (key == BTN_RIGHT)  btn_Pressed_Right();      
      }
    } else
    // display processor info & performance
    // if (clock_cycle_count % 10 == 0) 
    {
      char tmp[20];
      float freq;
        
      lcd.setCursor(0, 0);
      // lcd.print(clock_cycle_count);
      sprintf(tmp, "A=%0.4X D=%0.2X", uP_ADDR, DATA_OUT);
      lcd.print(tmp);
      lcd.setCursor(0,1);
      freq = (float) clock_cycle_count / (millis() - uP_start_millis + 1);
      lcd.print(freq);  lcd.print(" kHz   Z80");
    }
  }
  // Service serial port incoming characters.
  //
  serialEvent0();
    
}
```

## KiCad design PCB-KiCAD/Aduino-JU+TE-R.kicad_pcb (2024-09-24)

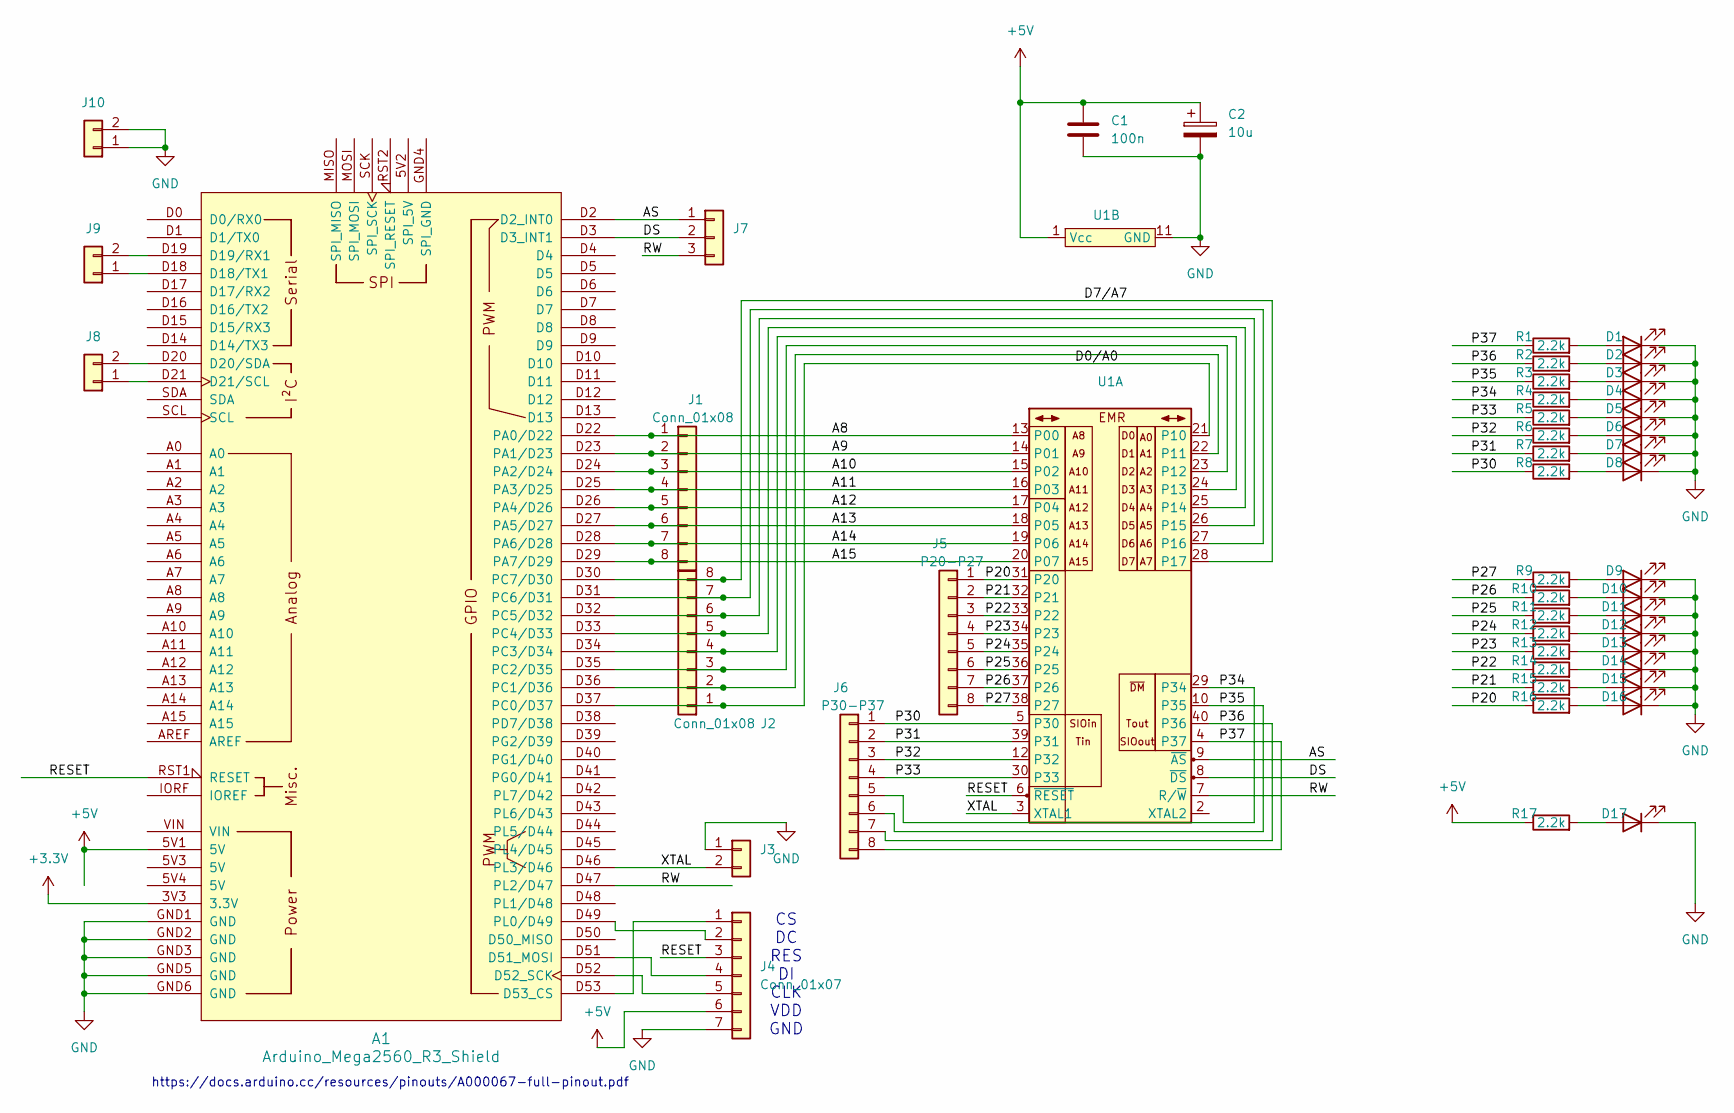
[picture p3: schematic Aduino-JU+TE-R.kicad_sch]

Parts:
A1: Arduino_Mega2560_R3_Shield
C1: 100n; C_0603_1608Metric_Pad1.08x0.95mm_HandSolder
C2: 10u; CP_EIA-2012-15_AVX-P_Pad1.30x1.05mm_HandSolder
D1, D2, D3, D4, D5, D6, D7, D8, D9, D10, D11, D12, D13, D14, D15, D16, D17: LED; LED_0603_1608Metric_Pad1.05x0.95mm_HandSolder
J1, J2: Conn_01x08; PinHeader_1x08_P2.54mm_Vertical
J3, J8, J9, J10: Conn_01x02; PinSocket_1x02_P2.54mm_Vertical
J4: Conn_01x07; PinHeader_1x07_P2.54mm_Vertical
J5: P20-P27; PinHeader_1x08_P2.54mm_Vertical
J6: P30-P37; PinHeader_1x08_P2.54mm_Vertical
J7: Conn_01x03; PinHeader_1x03_P2.54mm_Vertical
R1, R2, R3, R4, R5, R6, R7, R8, R9, R10, R11, R12, R13, R14, R15, R16, R17: 2.2k; R_0603_1608Metric_Pad0.98x0.95mm_HandSolder
U1: DIP-40_W15.24mm

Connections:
+3.3V: A1.3V3 (3.3V)
+5V: A1.5V1 (5V), C1.1, C2.1, J4.6, R17.1, U1.1 (Vcc)
/A8: A1.D22 (PA0/D22), J1.1, U1.13 (P00)
/A9: A1.D23 (PA1/D23), J1.2, U1.14 (P01)
/A10: A1.D24 (PA2/D24), J1.3, U1.15 (P02)
/A11: A1.D25 (PA3/D25), J1.4, U1.16 (P03)
/A12: A1.D26 (PA4/D26), J1.5, U1.17 (P04)
/A13: A1.D27 (PA5/D27), J1.6, U1.18 (P05)
/A14: A1.D28 (PA6/D28), J1.7, U1.19 (P06)
/A15: A1.D29 (PA7/D29), J1.8, U1.20 (P07)
/AS: A1.D2 (D2_INT0), J7.1, U1.9 (~AS)
/D0/A0: A1.D37 (PC0/D37), J2.1, U1.21 (P10)
/D7/A7: A1.D30 (PC7/D30), J2.8, U1.28 (P17)
/DS: A1.D3 (D3_INT1), J7.2, U1.8 (~DS)
/P20: J5.1, R16.1, U1.31 (P20)
/P21: J5.2, R15.1, U1.32 (P21)
/P22: J5.3, R14.1, U1.33 (P22)
/P23: J5.4, R13.1, U1.34 (P23)
/P24: J5.5, R12.1, U1.35 (P24)
/P25: J5.6, R11.1, U1.36 (P25)
/P26: J5.7, R10.1, U1.37 (P26)
/P27: J5.8, R9.1, U1.38 (P27)
/P30: J6.1, R8.1, U1.5 (P30)
/P31: J6.2, R7.1, U1.39 (P31)
/P32: J6.3, R6.1, U1.12 (P32)
/P33: J6.4, R5.1, U1.30 (P33)
/P34: J6.5, R4.1, U1.29 (P34)
/P35: J6.6, R3.1, U1.10 (P35)
/P36: J6.7, R2.1, U1.40 (P36)
/P37: J6.8, R1.1, U1.4 (P37)
/RESET: A1.RST1 (RESET), J4.3, U1.6 (~RESET)
/RW: A1.D47 (PL2/D47), J7.3, U1.7 (R/~W)
/XTAL: A1.D46 (PL3/D46), J3.2, U1.3 (XTAL1)
GND: A1.GND1 (GND), A1.GND2 (GND), A1.GND3 (GND), A1.GND5 (GND), A1.GND6 (GND), C1.2, C2.2, D1.1 (K), D2.1 (K), D3.1 (K), D4.1 (K), D5.1 (K), D6.1 (K), D7.1 (K), D8.1 (K), D9.1 (K), D10.1 (K), D11.1 (K), D12.1 (K), D13.1 (K), D14.1 (K), D15.1 (K), D16.1 (K), D17.1 (K), J3.1, J4.7, J10.1, J10.2, U1.11 (GND)
unnamed: A1.D18 (D18/TX1), J9.1
unnamed: A1.D19 (D19/RX1), J9.2
unnamed: A1.D20 (D20/SDA), J8.2
unnamed: A1.D21 (D21/SCL), J8.1
unnamed: A1.D51 (D51_MOSI), J4.4
unnamed: A1.D52 (D52_SCK), J4.5
unnamed: A1.D53 (D53_CS), J4.1
unnamed: A1.D36 (PC1/D36), J2.2, U1.22 (P11)
unnamed: A1.D35 (PC2/D35), J2.3, U1.23 (P12)
unnamed: A1.D34 (PC3/D34), J2.4, U1.24 (P13)
unnamed: A1.D33 (PC4/D33), J2.5, U1.25 (P14)
unnamed: A1.D32 (PC5/D32), J2.6, U1.26 (P15)
unnamed: A1.D31 (PC6/D31), J2.7, U1.27 (P16)
unnamed: A1.D49 (PL0/D49), J4.2
unnamed: D1.2 (A), R1.2
unnamed: D2.2 (A), R2.2
unnamed: D3.2 (A), R3.2
unnamed: D4.2 (A), R4.2
unnamed: D5.2 (A), R5.2
unnamed: D6.2 (A), R6.2
unnamed: D7.2 (A), R7.2
unnamed: D8.2 (A), R8.2
unnamed: D9.2 (A), R9.2
unnamed: D10.2 (A), R10.2
unnamed: D11.2 (A), R11.2
unnamed: D12.2 (A), R12.2
unnamed: D13.2 (A), R13.2
unnamed: D14.2 (A), R14.2
unnamed: D15.2 (A), R15.2
unnamed: D16.2 (A), R16.2
unnamed: D17.2 (A), R17.2

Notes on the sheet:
https://docs.arduino.cc/resources/pinouts/A000067-full-pinout.pdf
CS DC RES DI CLK VDD GND

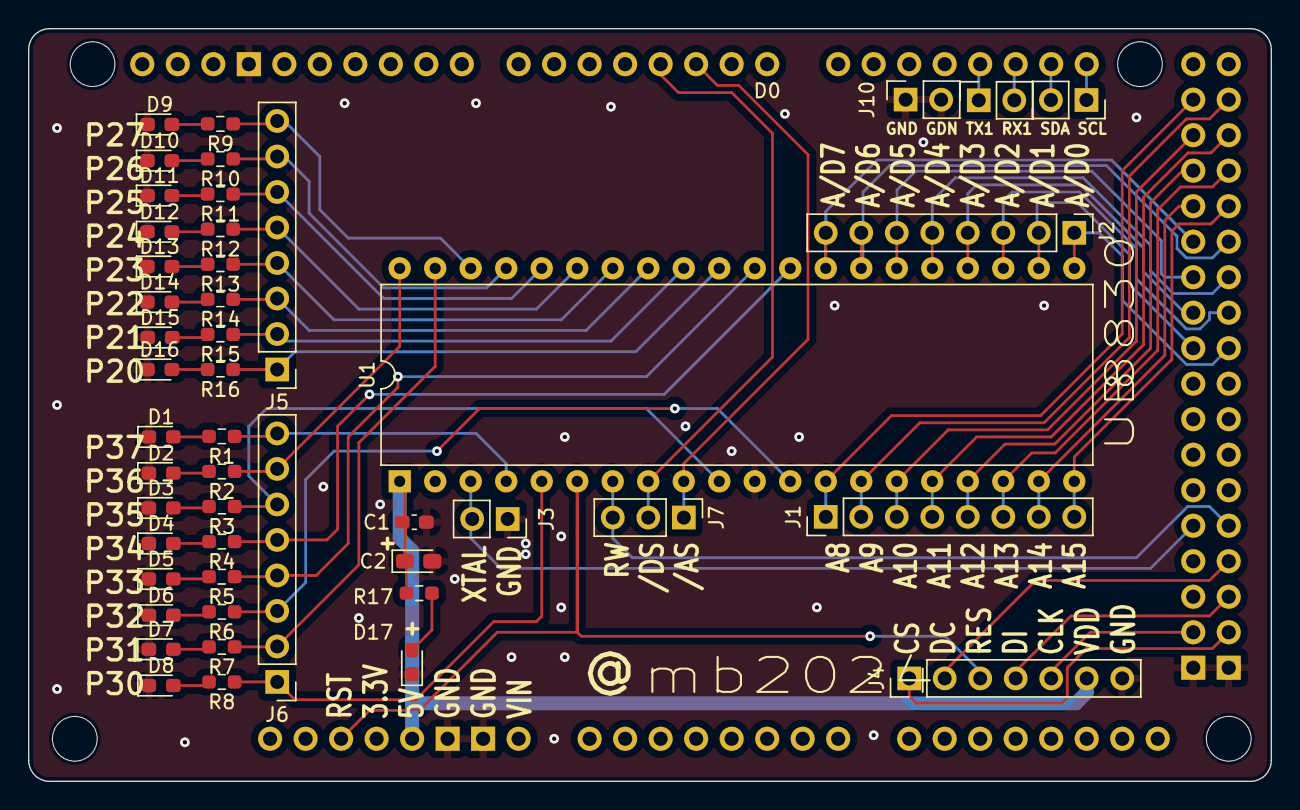
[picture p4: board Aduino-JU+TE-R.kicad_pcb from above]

Board: 2 copper layers, 88.9 x 53.8 mm, 48 parts (0 on the bottom side), 64 nets.

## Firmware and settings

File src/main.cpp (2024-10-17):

#include <Arduino.h>

#include <SPI.h>
#include <U8g2lib.h>

#include <mbLog.h>
#include <elapsedMillis.h>

// | D53 | CS |
// | D49 | DC |
// | D51(mosi) | DI |
// | D52(sclk) | CLK |

const uint8_t pinCS = 53;
const uint8_t pinDC = 49;
const uint8_t pinMOSI = 51;
const uint8_t pinSCLK = 52;

U8G2_SH1106_128X64_NONAME_F_4W_HW_SPI u8g2(U8G2_R0, /* cs=*/ pinCS, /* dc=*/ pinDC);


// UB8833 connections

#define DIR_IN  0x00
#define DIR_OUT 0xFF
#define DATA_DIR   DDRC
#define ADDR_H_DIR DDRA
#define ADDR_L_DIR DDRC // same as data, must be latched with AS

#define DATA_OUT (PORTC)
#define DATA_IN  (PINC)
#define ADDR_L   (PINC)
#define ADDR_H   (PINA)

// PORTA - UB8833 High Adr
// PORTC - UB8833 Low Adr / Data

const uint8_t pinAS = 2;
const uint8_t pinDS = 3;
const uint8_t pinRST = 45;
const uint8_t pinXTAL = 46;
const uint8_t pinRW = 47;

elapsedMillis emDisplay = 0;

void setup()
{
    Serial.begin(115200);
    SPI.begin();
    u8g2.begin();
    u8g2.setFont(u8g2_font_5x7_tr);

    DATA_DIR = DIR_IN;
    ADDR_H_DIR = DIR_IN;

    pinMode(pinAS, INPUT);
    pinMode(pinDS, INPUT);
    pinMode(pinRST, OUTPUT);
    pinMode(pinRW, INPUT);
    pinMode(pinXTAL, OUTPUT);
    digitalWrite(pinRST, HIGH);
    // analogWrite(pinXTAL, 128); // clock with 50%

    delay(10000);
    LOG <<"This is the ent." <<LOG.endl;
}

uint32_t clkcount = 0;
int as = 0, oldas = 0;
int ds = 0, oldds = 1;
int rw = 0;
uint16_t addr = 0;

void cpureset()
{
    // Reset should be kept low for 3 full clock cycles ???
    digitalWrite(pinRST, LOW);    delay(1);
    for(int i = 0; i < 8; i++)
    {
        digitalWrite(pinXTAL, LOW);
        digitalWrite(pinXTAL, HIGH);
    }
    digitalWrite(pinRST, HIGH);    delay(1);

    oldas = digitalRead(pinAS);
    oldds = digitalRead(pinDS);

    clkcount = 0;
}

// just run the clock...
int cpucycle_dummy()
{
    int i = 0;
    for(i = 0; i < 8; i++)
    {
        digitalWrite(pinXTAL, LOW);
        digitalWrite(pinXTAL, HIGH);
        clkcount++;
    }
    return i;
}

int cpucycle()
{
    int i = 0;
    for(i = 0; i < 11; i++)
    {
        digitalWrite(pinXTAL, LOW);    delay(1);
        digitalWrite(pinXTAL, HIGH);    delay(1);
        clkcount++;

        as = digitalRead(pinAS);
        if(oldas == 0 && as == 1)
            break;
        oldas = as;
    }
    // as strobe, read rw and low adr
    rw = digitalRead(pinRW);
    addr = (ADDR_H << 8) | ADDR_L;


    oldds = 1;
    for(i = 0; i < 11; i++)
    {
        digitalWrite(pinXTAL, LOW);    delay(1);
        digitalWrite(pinXTAL, HIGH);    delay(1);
        clkcount++;

        ds = digitalRead(pinDS);
        if(oldds == 1 && ds == 0)
            break;
        oldds = ds;
    }
    // LOG <<clkcount <<" ds:" <<ds <<" rw:" <<rw <<" addr:" <<LOG.hex <<addr <<LOG.dec <<LOG.endl;


    // if reading, output [addr]

    oldds = 0;
    for(i = 0; i < 11; i++)
    {
        digitalWrite(pinXTAL, LOW);    delay(1);
        digitalWrite(pinXTAL, HIGH);    delay(1);
        clkcount++;

        ds = digitalRead(pinDS);
        if(oldds == 0 && ds == 1)
            break;
        oldds = ds;
    }
    // LOG <<clkcount <<" ds:" <<ds <<" rw:" <<rw <<" addr:" <<LOG.hex <<addr <<" data:" <<DATA_IN <<LOG.dec <<LOG.endl;

    if(addr | DATA_IN)
    {
        LOG <<clkcount <<" ds:" <<ds <<" rw:" <<rw <<" addr:" <<LOG.hex <<addr <<" data:" <<DATA_IN <<LOG.dec <<LOG.endl;
        LOG <<"---" <<LOG.endl;
    }

    return i;
}

void loop()
{
    if(emDisplay > 100)
    {
        emDisplay = 0;

        LOG <<"---------------------" <<LOG.endl;
        LOG <<"Hello Mega Comp Ju+Te r" <<LOG.endl;


        // start 8833 and watch
        cpureset();

        for(int i = 0; i < 10000; i++)
        {
            int clks = cpucycle_dummy();
        }

        // for(int i = 0; i < 10000; i++)
        // {
        //     int clks = cpucycle();
        //     if(clks < 20)
        //     {
        //         if(clkcount % 1000 > 980)
        //         {
        //             LOG <<"clkcount:" <<clkcount <<LOG.endl;
        //         }
        //         if(addr > 0)
        //         {
        //             LOG <<"addr after " <<i <<" cpu cygles" <<LOG.endl;
        //             break;
        //         }
        //     }
        //     else
        //     {
        //         LOG <<"cpucycle error" <<LOG.endl;
        //         break;
        //     }
        // }
        // for(int i = 0; i < 10; i++)
        // {
        //     int clks = cpucycle();
        // }

        char sbuf[20];
        u8g2.clearDisplay();
        u8g2.setCursor(7,7);
        u8g2.setDrawColor(1);
        u8g2.drawStrX2(0,16,"JU+TE");

        snprintf(sbuf, 20, "A:%x D:%x", addr, 0);
        u8g2.drawStr(0,30, sbuf);
        // u8g2.drawLine(0,0, 127, 63);
        u8g2.updateDisplay();

    }
}
